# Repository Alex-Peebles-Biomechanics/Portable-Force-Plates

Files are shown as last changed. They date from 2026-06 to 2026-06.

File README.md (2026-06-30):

# Portable-Force-Plates
This repository contains all hardware and software documents needed to replicate the portable force plate system introduced in the publication shown below. Software was implemented in C++ on the systems embedded microcontroller (Arduino) and in MATLAB on a computer connected to the system with a USB cable. The STL files have standard mm units and can be produced on any desktop 3D printer using PLA filament. The PCB files can be uploaded to websites such as JLCPCB.com to manufacture the circuit boards used in the device. 

For more information on the force plate system design and implementation, please see the publication below.

Peebles, Alexander T. (2026) Design and Validation of a Human Movement Biomechanics Screening Program. In Review at Journal of Biomechanical Engineering.

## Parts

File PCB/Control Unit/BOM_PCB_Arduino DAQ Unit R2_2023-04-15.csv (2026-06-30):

ID | Name | Designator | Footprint | Quantity | Manufacturer Part | Manufacturer | Supplier | Supplier Part | Price
1 | HDR-F-2.54_1x15 | ARD_L,ARD_R | HDR-F-2.54_1X15 | 2 |  |  | LCSC | C124408 | 0.034
2 | 10k | BTN,ROT_1,ROT_2 | R_AXIAL-0.4 | 3
3 | 220 | GLED_220,RLCD_220,RLED_220 | R_AXIAL-0.4 | 3
4 | LED-TH-3mm_G | GLED | LED-TH_BD3.0_GREEN | 1 | 204-10SYGD/S530-E3 | EVERLIGHT(台湾亿光) |  | C85161 | 0.005
5 | HDR-F-2.54_1x16 | LCD | HDR-F-2.54_1X16 | 1 |  |  | LCSC | C66987 | 0.017
6 | DB9_Female | LEFT_DB9,RIGHT_DB9 | DSUB-TH_DMR-9S | 2 |  | Ckmtw(灿科盟) | LCSC | C141882 | 0.048
7 | R_3386P_EU | POT | RES-ADJ-TH_3386P | 1 |  |  | LCSC
8 | LED-TH-3mm_R | REDLED | LED-TH_BD3.0_RED | 1 | 204-10SDRD/S530-A3-L | EVERLIGHT(台湾亿光) | LCSC | C84774 | 0.006
9 | 1k | SPKR | R_AXIAL-0.3 | 1
10 | 2N3904(TO-92) | SPKR_TR | TO-92-3_L5.1-W4.1-P1.27-L | 1 | 2N3904 | SEMTECH | LCSC | C118538 | 0.002
11 | PEC11R-4015F-S0024 | SW1 | SW-TH_PEC11R-4XXXF-SXXXX | 1 | PEC11R-4015F-S0024 | BOURNS | LCSC | C143789 | 0.376
12 | 1k | SPKR_1K | R_AXIAL-0.4 | 1

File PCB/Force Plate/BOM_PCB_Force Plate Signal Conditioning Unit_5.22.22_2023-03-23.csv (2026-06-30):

ID | Name | Designator | Footprint | Quantity | Manufacturer Part | Manufacturer | Supplier | Supplier Part | Price
1 | HDR-F-2.54_1x4 | BL,BR,TL,TR | HDR-F-2.54_1X4 | 4 |  |  | LCSC | C225501 | 0.013
2 | 24.9K | BLNF,BLPF,BRNF,BRPF,TLNF,TLPF,TRNF,TRPF | R0603 | 8 | 0603WAF2492T5E | UniOhm | LCSC | C25962
3 | 40.2K | BLNO,BLPO,BLRC,BLSF,BRNO,BRPO,BRRC,BRSF,TLNO,TLPO,TLRC,TLSF,TRNO,TRPO,TRRC,TRSF | R0603 | 16 | 0603WAF4022T5E | UniOhm | LCSC | C12447
4 | LM358DT | BL_IN,BL_OUT,BR_IN,BR_OUT,TL_IN,TL_OUT,TR_IN,TR_OUT | SOIC-8_L5.0-W4.0-P1.27-LS6.0-BL | 8 | LM358DT | STMicroelectronics | LCSC | C9418 | 0.018
5 | 220 | BL_RG,BR_RG,TL_RG,TR_RG | R_AXIAL-0.4 | 4
6 | DB9_Female | DB1 | DSUB-TH_DMR-9S | 1 |  | Ckmtw(灿科盟) | LCSC | C141882 | 0.048
7 | R_3386P_EU | BL_POT,BR_POT,TL_POT,TR_POT | RES-ADJ-TH_3386P | 4 |  |  | LCSC

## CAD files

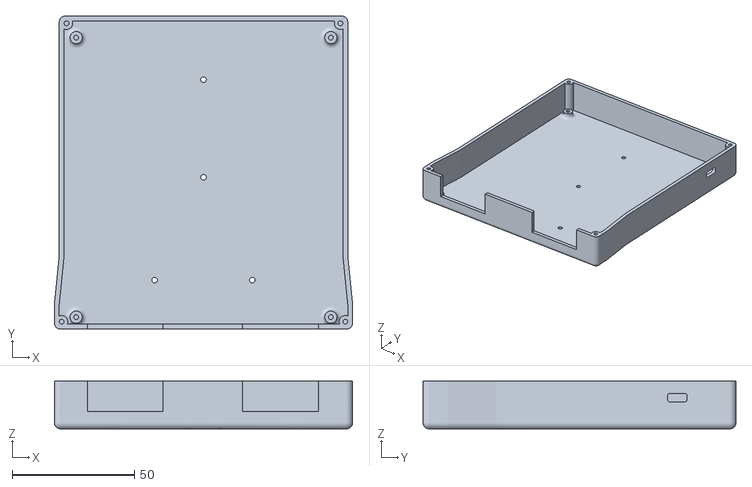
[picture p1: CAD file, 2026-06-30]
CAD/Control Unit/Base.stl
122.0 x 128.0 x 19.5

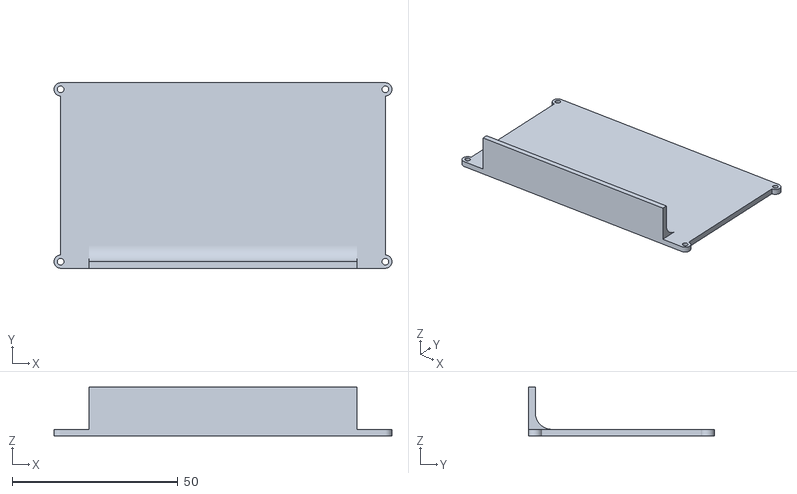
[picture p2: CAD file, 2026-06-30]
CAD/Force Plate/Signal Conditioning PCB Enclosure Top.stl
102.0 x 56.0 x 14.8

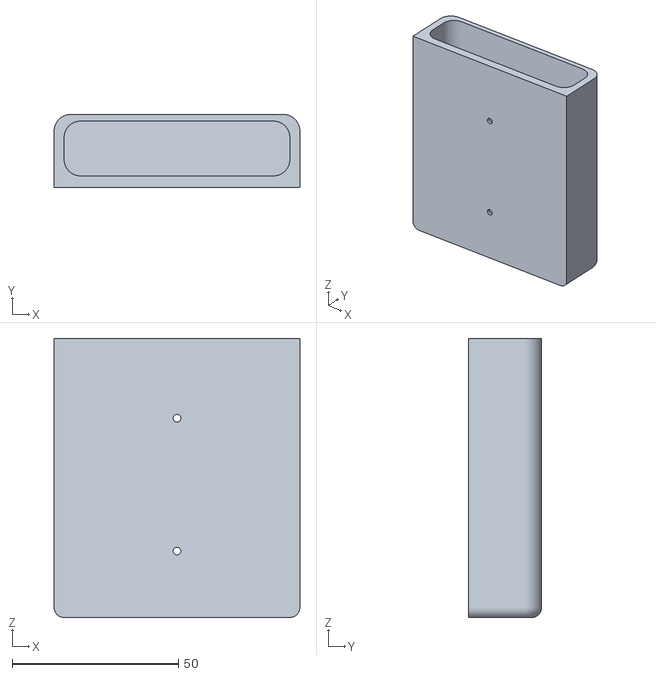
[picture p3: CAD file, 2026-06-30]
CAD/Control Unit/Battery Mount.stl
74.0 x 22.0 x 84.0

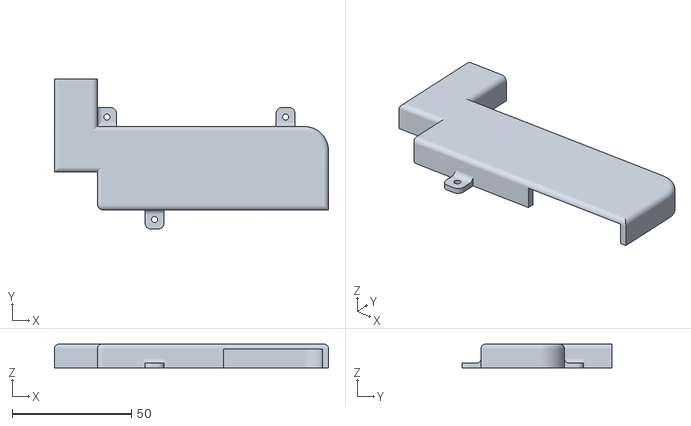
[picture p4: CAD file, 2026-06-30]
CAD/Force Plate/middle cover right.stl
115.0 x 63.0 x 10.0

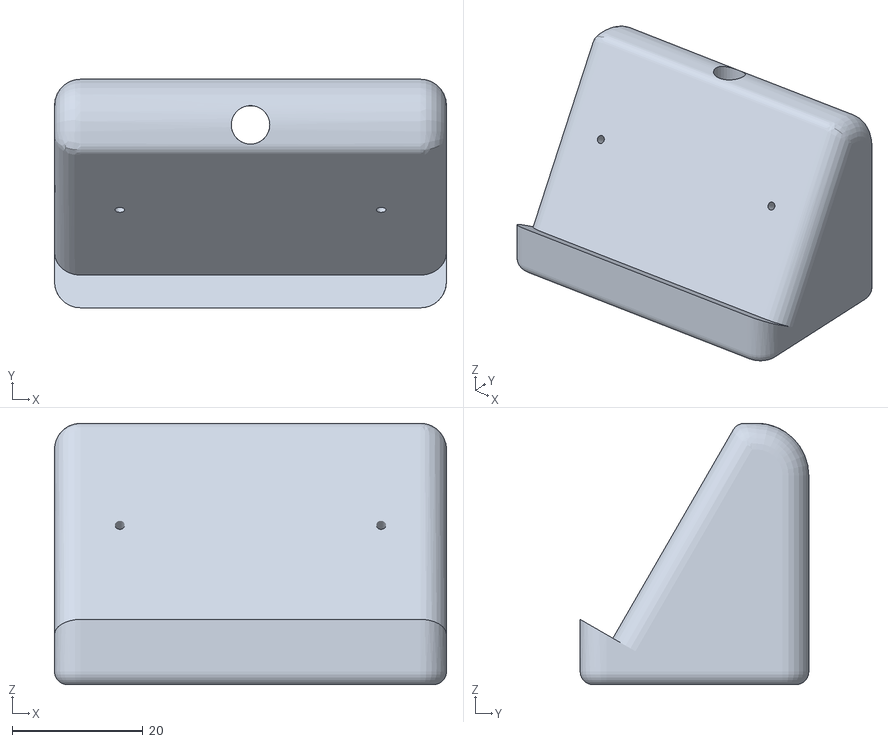
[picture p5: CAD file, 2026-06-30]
CAD/Control Unit/Tripod Mount.stl
60.0 x 35.0 x 40.0

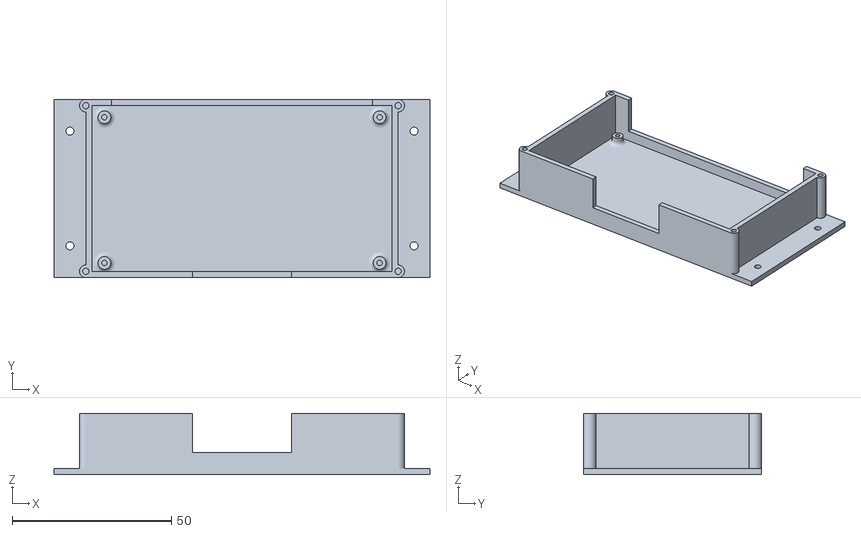
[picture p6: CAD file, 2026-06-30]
CAD/Force Plate/Signal Conditioning PCB Enclosure Base.stl
118.0 x 56.0 x 19.2

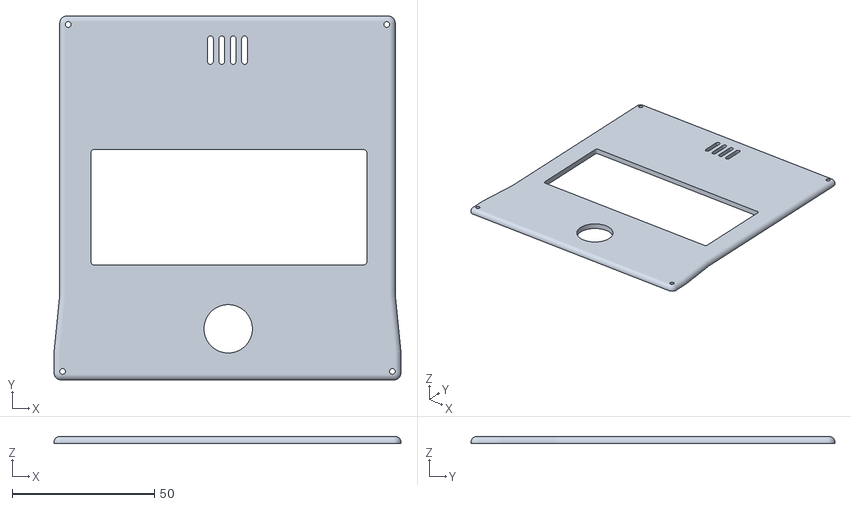
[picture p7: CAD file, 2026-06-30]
CAD/Control Unit/Top.stl
122.0 x 128.0 x 2.50

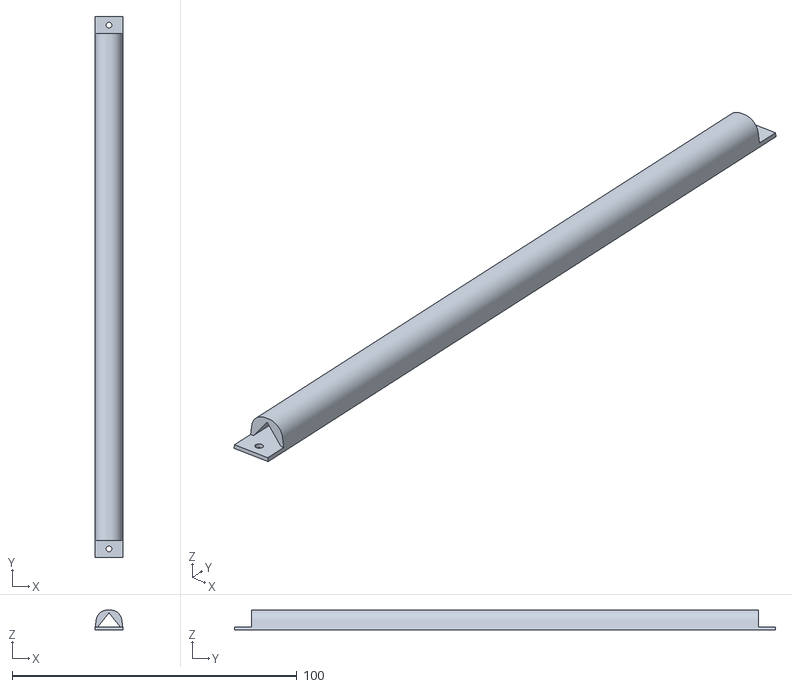
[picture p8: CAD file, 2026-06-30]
CAD/Force Plate/Side Tubes.stl
10.0 x 190.0 x 7.00

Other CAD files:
CAD/Force Plate/middle cover left.stl

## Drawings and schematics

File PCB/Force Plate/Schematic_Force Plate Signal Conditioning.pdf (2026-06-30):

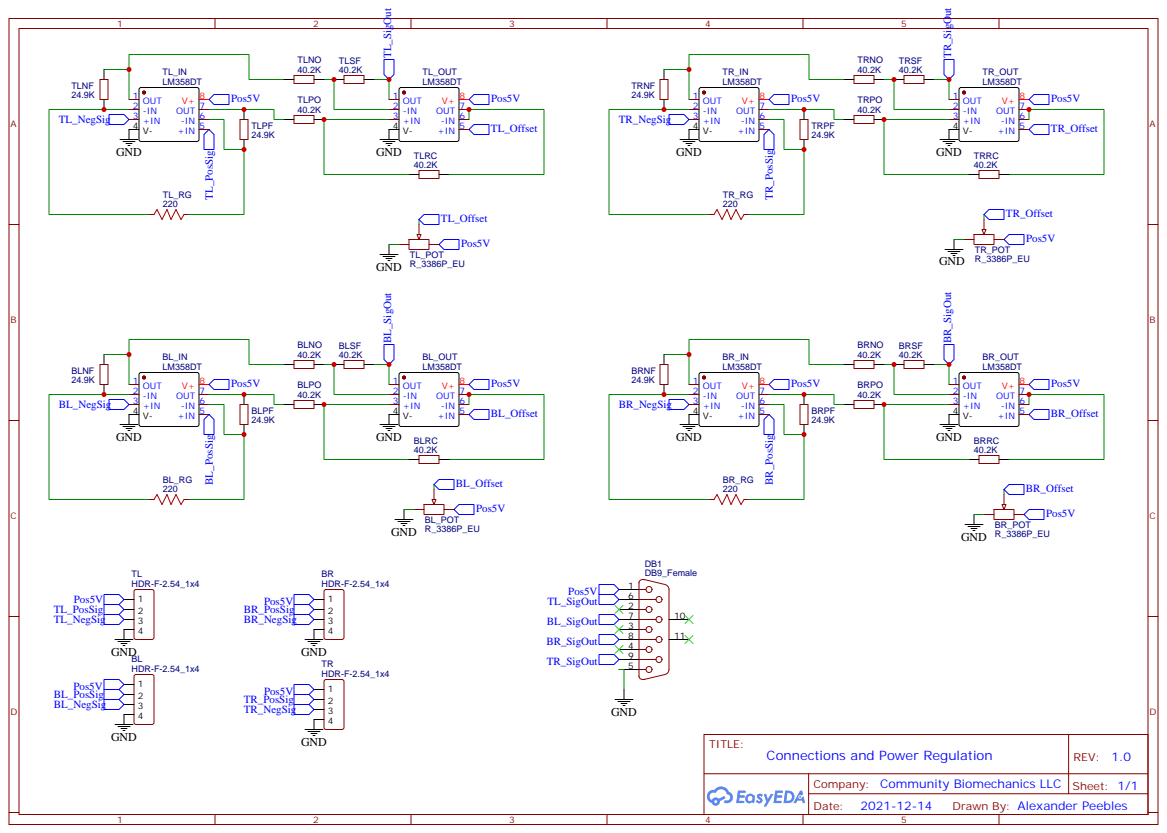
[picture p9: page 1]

Company: Community Biomechanics LLC

Drawn By: Alexander Peebles

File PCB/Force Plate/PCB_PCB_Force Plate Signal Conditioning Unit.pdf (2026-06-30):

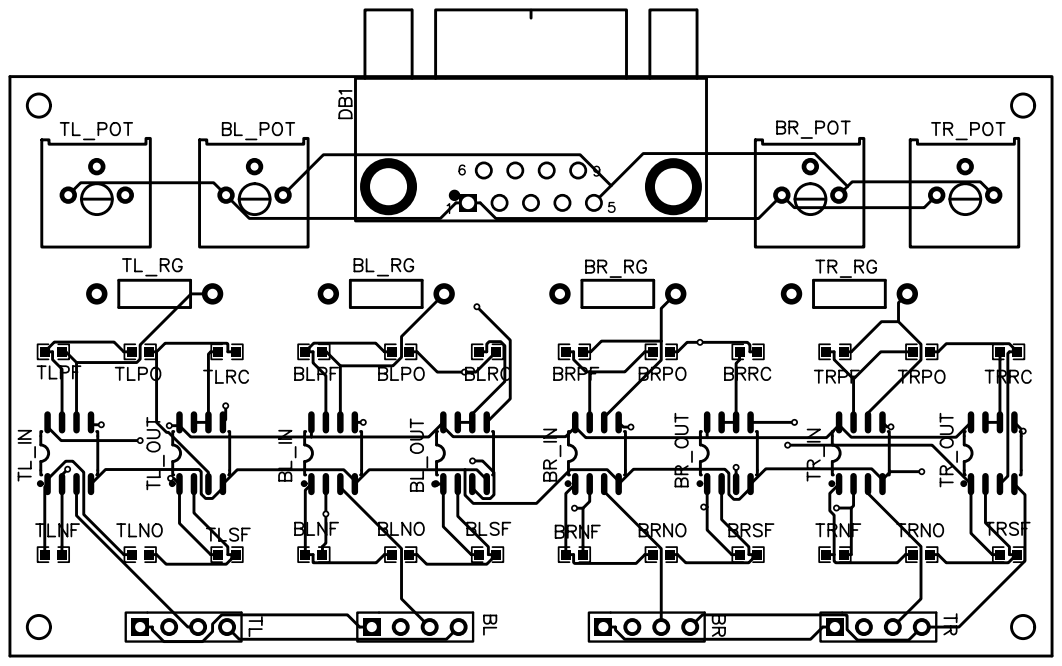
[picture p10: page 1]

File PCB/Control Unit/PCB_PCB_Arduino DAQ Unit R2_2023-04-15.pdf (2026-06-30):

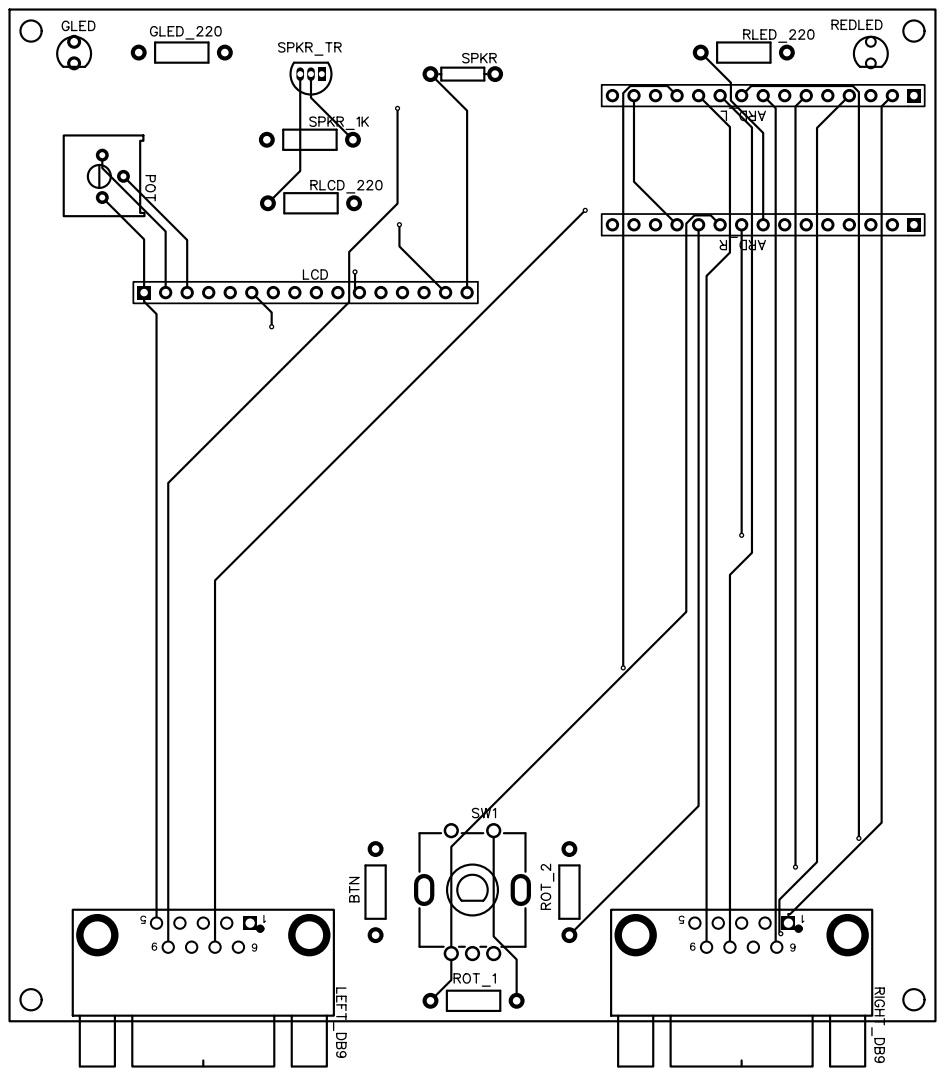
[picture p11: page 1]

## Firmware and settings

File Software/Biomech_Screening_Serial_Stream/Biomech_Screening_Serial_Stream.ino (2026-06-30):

#include <LiquidCrystal.h>
LiquidCrystal lcd(13, 12, 11, 10, 9, 8);

// Temporary calibration coefficients, will set later (unit N/ADC)
float m_L_TL = 0.9042, m_L_BL = 0.9184, m_L_BR = 0.9005, m_L_TR = 0.9200;
float m_R_TL = 0.9169, m_R_BL = 0.8968, m_R_BR = 0.8882, m_R_TR = 0.9112;

const int L_TL_Pin = A0;
const int L_BL_Pin = A1;
const int L_BR_Pin = A2;
const int L_TR_Pin = A3;
const int R_TL_Pin = A4;
const int R_BL_Pin = A5;
const int R_BR_Pin = A6;
const int R_TR_Pin = A7;

const int enterButton = 4;
const int CLK = 3;
const int DT =  2;
int currentStateA;
int lastStateA;

const int GreenLED = 7;
const int buzzerPin = 6;
const int RedLED = 5;

const int debounce = 250;
const int IC_Thresh = 125;
const int TO_Thresh = 100;

float L_TL_0, L_BL_0, L_BR_0, L_TR_0, R_TL_0, R_BL_0, R_BR_0, R_TR_0;
float L_TL, L_BL, L_BR, L_TR, R_TL, R_BL, R_BR, R_TR;

int DominantLimb = 1; // 1-right, 2-left
int testPlate = 1;  // 1-right, 2-left

struct datastoreForce {
  float Time;
  float leftForce;
  float rightForce;
};

struct datastoreCOP {
  float Time;
  float COPx;
  float COPy;  
};


int Fs = 500;
float bodyweight = 1;
int trialLength = 20;
String cmd;
unsigned long previousMillis, startingMillis;

float PlateNumberChoices[] = {1, 1, 22};
int leftPlateSelect = 1;
int rightPlateSelect = 1;

const char *mainMenuChoices[] = {"1. New Subject", "2. Tare plates", "3. Display force", "4. Display raw"};
int mainMenuSelect = 1;

const char *studySelectChoices[] = {"1. Balance", "2. Athletics"};
float PIDChoices[] = {1, 1, 100};
int studySelect = 1;
int PIDSelect = 1;

// const char *movementMenuChoices[] = {"1. Balance - EO", "2. Balance - EC", "3. Squat", "4. DJ vert jump", "5. DL DVJ", "6. DL drop landing", "7. SL vert jump", "8. SL DVJ", "9. SL drop landing","Exit"};
const char *movementMenuChoices[] = {"1. Balance - EO", "2. Balance - EC", "3. Squat", "Exit"};
String movementChoice;
const char *limbMenuChoices[] = {"1. Right", "2. Left"};

const char *screenStartMenuChoices[] = {"1. Begin", "2. New movement", "3. New session", "4. Exit"};
String incomingMsg;

int  MovementSelected = 1, mainMenu = 1, trainingMenuSelect = 1, screenStartChoice = 1, trainStartChoice = 1;
bool updateLCD = true, passed_Trial = true;


float leftForce, rightForce, Force, Time, COPx, COPy, COPx_prev, COPy_prev, ML_Range, AP_Range, swayVel;

int state, count, page;
bool IC_Prev1;

void setup() {
  Serial.begin(28800);
  analogReadResolution(12);
  
  pinMode(CLK,INPUT);
  pinMode(DT,INPUT);
  pinMode(enterButton, INPUT);
  lastStateA = digitalRead(CLK);
  
  pinMode(GreenLED,OUTPUT);
  pinMode(RedLED, OUTPUT);
    
  lcd.begin(20, 4);
  lcd.blink();
  
  leftPlateSelect = FloatMenu("Left Plate Number:", " ", PlateNumberChoices, leftPlateSelect);
  rightPlateSelect = FloatMenu("Right Plate Number:", " ", PlateNumberChoices, rightPlateSelect);
  updateSlopes();
  CalibrateForcePlates();

  lcd.clear();
  lcd.setCursor(0, 0);
  lcd.print("Waiting for CPU");
  lcd.setCursor(0, 1);
  lcd.print("Connection ");

  while (Serial.available() == 0) {}
  String Message = Serial.readStringUntil(' ');
}


void loop() {
  mainMenuSelect = StringMenu("Select:", mainMenuChoices, 4, mainMenuSelect); 
    if (mainMenuSelect == 1){
      Screen_1();
    } else if (mainMenuSelect == 2) {
      CalibrateForcePlates();
    } else if (mainMenuSelect == 3) {
      displayForce();
    } else if (mainMenuSelect == 4) {
      displayRaw();
    }  
}

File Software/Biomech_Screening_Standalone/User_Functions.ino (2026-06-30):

void Screen_1() { 
  recordBodyweight();
  Screen_2();
}

void Screen_2() { // select movement
  MovementSelected = StringMenu("Select movement:", movementMenuChoices, 4, MovementSelected);
  movementChoice = (String) movementMenuChoices[MovementSelected - 1];
  movementChoice.remove(0, 3);

    if (MovementSelected == 1 || MovementSelected == 2) { // balance task
      Fs = 20;
      Screen_Balance();
    } else if (MovementSelected == 3){ // squatting task..
      Fs = 50;
      Screen_Force();
    } else {
      // should exit back to start menu (new subject, etc)
    }
}

void Screen_Balance(){
  lcd.clear();
  lcd.setCursor(0, 0);
  if (MovementSelected == 1){
    lcd.print("Balance: Eyes Open");    
  } else {
    lcd.print("Balance: Eyes Closed");
  }
  lcd.setCursor(0, 1);
  lcd.print("Stand on one plate");
  lcd.setCursor(0, 2);
  lcd.print("and press enter to");
  lcd.setCursor(0, 3);
  lcd.print("begin 30 sec trial");
 
  while (digitalRead(enterButton) == LOW) {}
  while (digitalRead(enterButton) == HIGH) {}
  delay(debounce);

  lcd.clear();
  lcd.setCursor(0, 0);
  readForce();
  if ((R_TL + R_BL + R_BR + R_TR) > (L_TL + L_BL + L_BR + L_TR)){
    testPlate = 1;
    lcd.print("Testing Right Plate");
  } else {
    testPlate = 2;
    lcd.print("Testing Left Plate");
  }

  trialLength = 30;
  state = 0;
  startingMillis = millis();
  previousMillis = millis();
  while ((int) (millis() - startingMillis) < (trialLength * 1000)) {
    
    count = 0, TL=0, TR=0, BL=0, BR=0;
    while ((millis() - previousMillis) < (1000.0/Fs)) {
     readForce();
     if (testPlate == 1) {
        TL += R_TL;
        BL += R_BL;
        BR += R_BR;
        TR += R_TR;
        count++;
      } else {
        TL += L_TL;
        BL += L_BL;
        BR += L_BR;
        TR += L_TR;
        count++;
      }           
    }    
    previousMillis = millis();

    TL = TL/count;
    BL = BL/count;
    BR = BR/count;
    TR = TR/count;

    COPx = ((width * TL + width * BL - width * BR - width * TR) / (TL + BL + BR + TR));
    COPy = ((length * TL - length * BL - length * BR + length * TR) / (TL + BL + BR + TR));
    
    if (state == 0) {
      COPx_prev = COPx;
      COPy_prev = COPy;
      state = 1;
    } else {
      pathLength += sqrt(pow((COPx - COPx_prev), 2) + pow((COPy - COPy_prev), 2));
      COPx_prev = COPx;
      COPy_prev = COPy;
    }
  }

  Time = (float) (millis() - startingMillis) / 1000;
  swayVel = pathLength / Time;

  lcd.clear();
  lcd.setCursor(0, 0);
  lcd.print("Balance Results");
  lcd.setCursor(0, 1);
  lcd.print("Sway Velocity:");
  lcd.setCursor(0, 2);
  lcd.print((String) swayVel + " (cm/s)");
  
  while (digitalRead(enterButton) == LOW) {}
  while (digitalRead(enterButton) == HIGH) {}
  delay(debounce);
  
  Screen_2();
}

void Screen_Force(){
  lcd.clear();
  lcd.setCursor(0, 0);
  lcd.print("Bodyweight Squats");
  lcd.setCursor(0, 1);
  lcd.print("Five reps, as low as");
  lcd.setCursor(0, 2);
  lcd.print("you can safely.");
  lcd.setCursor(0, 3);
  lcd.print("Press enter to begin");

  while (digitalRead(enterButton) == LOW) {}
  while (digitalRead(enterButton) == HIGH) {}
  delay(debounce);

  lcd.clear();
  lcd.setCursor(0, 0);
  lcd.print("TESTING...");
  lcd.setCursor(0, 1);
  lcd.print("Press enter to stop");
  lcd.setCursor(0, 2);

  trialLength = 30;
  state = 0;
  N = 1, AveSym = 0, PkForce = 0;
  float L_Imp = 0, R_Imp = 0;
  startingMillis = millis();
  previousMillis = millis();
  while (digitalRead(enterButton) == LOW) {
    
    count = 0, rightForce=0, leftForce=0;
    while ((millis() - previousMillis) < (1000.0/Fs)) {
     readForce();
     leftForce += (L_TL + L_BL + L_BR + L_TR);
     rightForce += (R_TL + R_BL + R_BR + R_TR);
     count++; 
    }
    previousMillis = millis();    
    
    leftForce = leftForce / count;
    rightForce = rightForce / count;
    totalForce = (leftForce + rightForce);
        
    if (totalForce > bodyweight){
      L_Imp = L_Imp + ((leftForce-L_Imp) / (N));
      R_Imp = R_Imp + ((rightForce-R_Imp) / (N));
      N++;
    }
  }  
  while (digitalRead(enterButton) == HIGH) {}
  delay(3*debounce);

  AveSym = 200 * (R_Imp - L_Imp)/(L_Imp + R_Imp);

  lcd.clear();
  lcd.setCursor(0, 0);
  lcd.print("Symmetry (%)"); 
  lcd.setCursor(0, 1);
  lcd.print("    " + (String) (AveSym)); 
  
  while (digitalRead(enterButton) == LOW) {}
  while (digitalRead(enterButton) == HIGH) {}
  delay(debounce);
  
  Screen_2();
}

void recordBodyweight() {
  lcd.clear();
  lcd.setCursor(0, 0);
  lcd.print("Stand on one plate");
  lcd.setCursor(0, 1);
  lcd.print("and press enter");
  lcd.setCursor(0, 2);
  lcd.print("to record bodyweight");
  while (digitalRead(enterButton) == LOW) {}
  while (digitalRead(enterButton) == HIGH) {}
  delay(debounce);
  
  L_TL = 0, L_BL = 0, L_BR = 0, L_TR = 0, R_TL = 0, R_BL = 0, R_BR = 0, R_TR = 0;
  count = 0;
  while(count < 100) {
    L_TL += ((float) analogRead(L_TL_Pin)) * m_L_TL + L_TL_0;
    L_BL += ((float) analogRead(L_BL_Pin)) * m_L_BL + L_BL_0;
    L_BR += ((float) analogRead(L_BR_Pin)) * m_L_BR + L_BR_0;
    L_TR += ((float) analogRead(L_TR_Pin)) * m_L_TR + L_TR_0;
    R_TL += ((float) analogRead(R_TL_Pin)) * m_R_TL + R_TL_0;
    R_BL += ((float) analogRead(R_BL_Pin)) * m_R_BL + R_BL_0;
    R_BR += ((float) analogRead(R_BR_Pin)) * m_R_BR + R_BR_0;
    R_TR += ((float) analogRead(R_TR_Pin)) * m_R_TR + R_TR_0;
    count++;
  }

  leftForce = (L_TL + L_BL + L_BR + L_TR) / count;
  rightForce = (R_TL + R_BL + R_BR + R_TR) / count;
  

  if (leftForce > rightForce){
    bodyweight = leftForce;
  } else {
    bodyweight = rightForce;
  }

  lcd.clear();
  lcd.setCursor(0, 0);  
  lcd.print("BW: " + (String) (int) (bodyweight*0.225) + " lb");
  lcd.setCursor(0, 1);
  lcd.print("Enter to accept");

  while (digitalRead(enterButton) == LOW) {}
  while (digitalRead(enterButton) == HIGH) {}
  delay(debounce);
}
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

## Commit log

2026-06-30 Add One_System_Validation.m for force plate analysis
2026-06-30 Add Biomech Screening Standalone Arduino code
2026-06-30 Add ReadMe file for STL files in mm format
2026-06-30 Add ReadMe file for Force Plate project
